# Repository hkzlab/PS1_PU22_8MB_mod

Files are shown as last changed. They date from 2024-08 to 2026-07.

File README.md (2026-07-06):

# PlayStation PU-22 8MB RAM Daughterboard

## DISCLAIMER

Any use of this project is **under your own responsibility**.
You will be responsible of checking the correct construction and functionality of your board.
By using this project You will agree that I cannot be held responsible if it will destroy any of your devices, damage your computer, burn down your house or whatever.

## Introduction

This daughter board replaces the single main RAM IC on your PU-22 motherboard with 4 2Mx8 ICs, shuffles some address lines and provides your PlayStation with 8MB of addressable memory.

I tested this on my european SCPH-7502 console, with a PU-22 motherboard in it. The board boots fine and all the 8MB are addressable.
It could work on other models too, but as of now, this is the only tested one.

### Support

If you wish to support me in building new hardware and software for old machines, [throw a few euros in my direction via Ko-Fi](https://ko-fi.com/hkzlab) ☕!

### 💰 Selling these boards 💰

I you want to contact me about selling this project, you can reach me via email at `0hkzUNDERSCOREprojects6ATposteoDOTnet` after properly fixing the email address by removing the digits and replacing the uppercase words with the proper characters.

**Contacts via other channels will be ignored**, as it means you did not read this document thoroughly.

"Collaborations" will boil down to the following:

- If you wish to produce and share this project at a loss or at cost, go for it. I am only asking for attribution and to let me know via email.
- If you want to do it for profit, let's discuss it. I'll probably settle for a rough 5% of the profit. Importing components is getting more expensive by the day, so this will contribute to me making future projects available for free.
- I will NOT do customer assistance for you or your customers. This is a hobby, not my job.

If this is not ok for you, you're cordially invited to go bother someone else :)

Authorized sellers will be listed in this README. If you find someone selling my boards without being listed here, it means they're stealing other people's work.

## Hardware

The board was designed with [KiCad](https://kicad.org/) EDA.

The board **MUST** be produced on a flexible PCB!

### Installation instructions

Disassemble your PlayStation, extract the motherboard and make sure the model is a PU-22.

⚠️WARNING⚠️: This mod probably works on all units with this type of RAM and processor, but it has been tested on PU-22 units only, as of now.

Assemble the daughterboard, soldering caps and memory ICs.
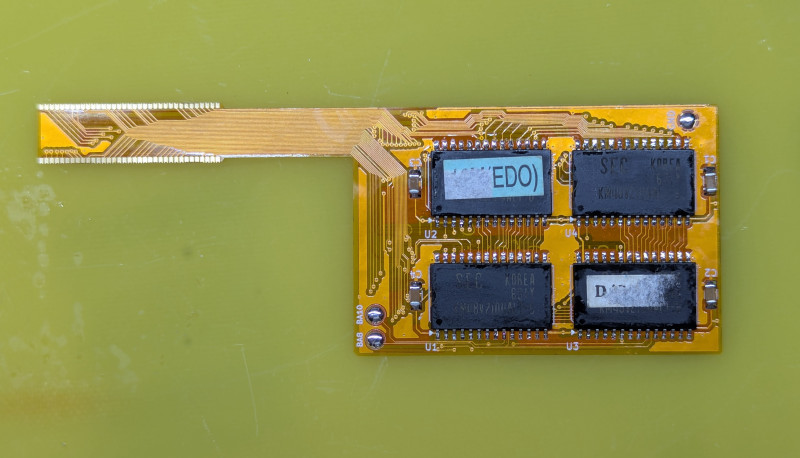
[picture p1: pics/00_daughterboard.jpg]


Desolder the inner shield covering the main ICs, including the RAM.

Cover the components around RAM "IC106" with kapton tape, to protect them during desoldering.
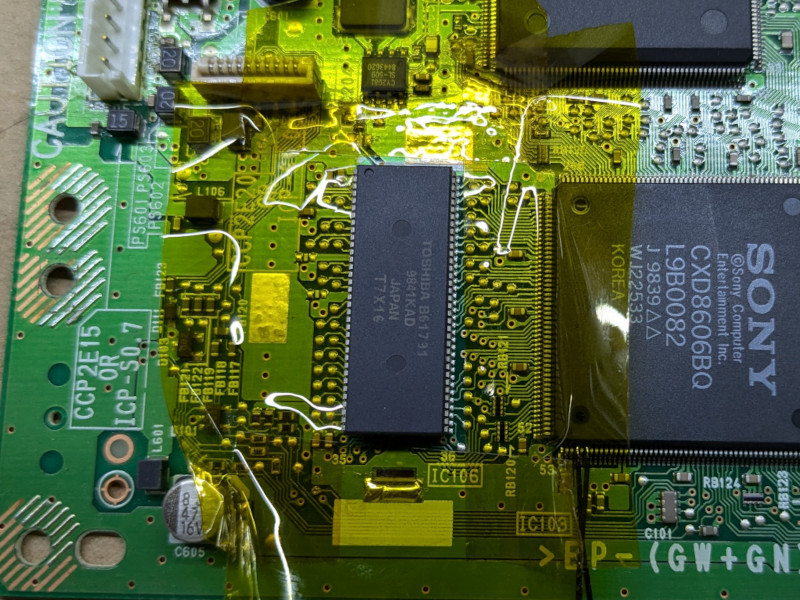
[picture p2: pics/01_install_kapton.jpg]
RAM + Kapton around it


Desolder the RAM IC using hot air, then clean the pads using flux and solder wick.
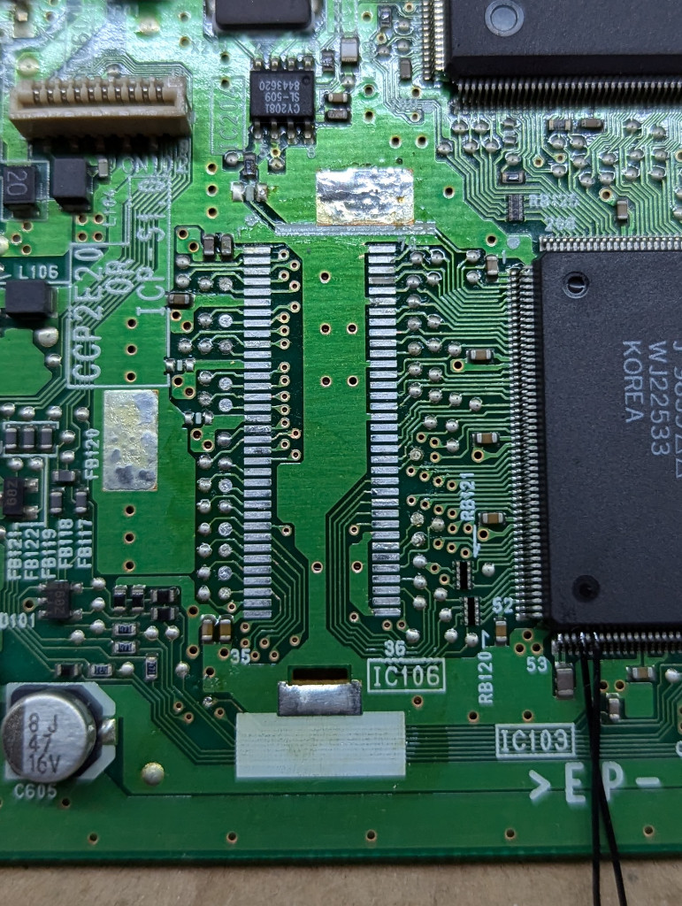
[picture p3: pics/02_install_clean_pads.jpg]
RAM desoldered, pads clean


Solder the board to the old RAM pads, make sure to solder the board in the correct orientation. Pin one has a tiny arrow printed on it, match it on pin 1 on the motherboard.
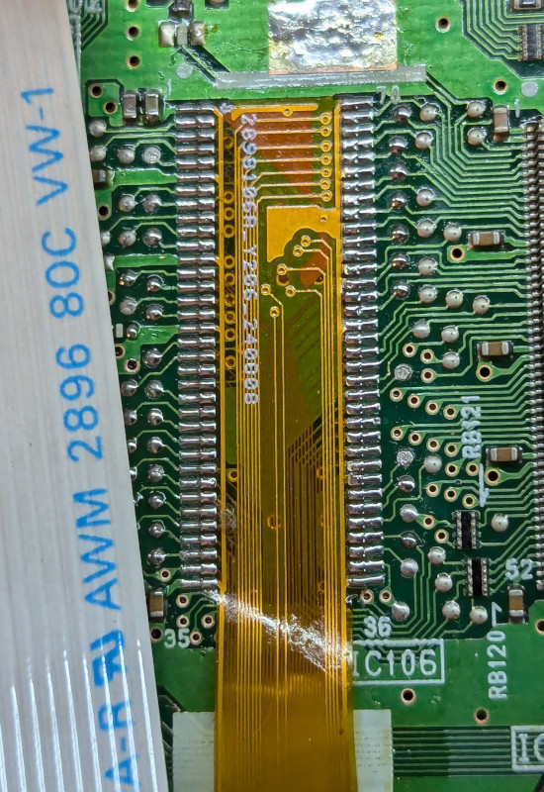
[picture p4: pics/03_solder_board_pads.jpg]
soldered pads


You now need to solder two wires to the CPU, to extract A10 and A8. A10 is pin 56, A8 is pin 58.
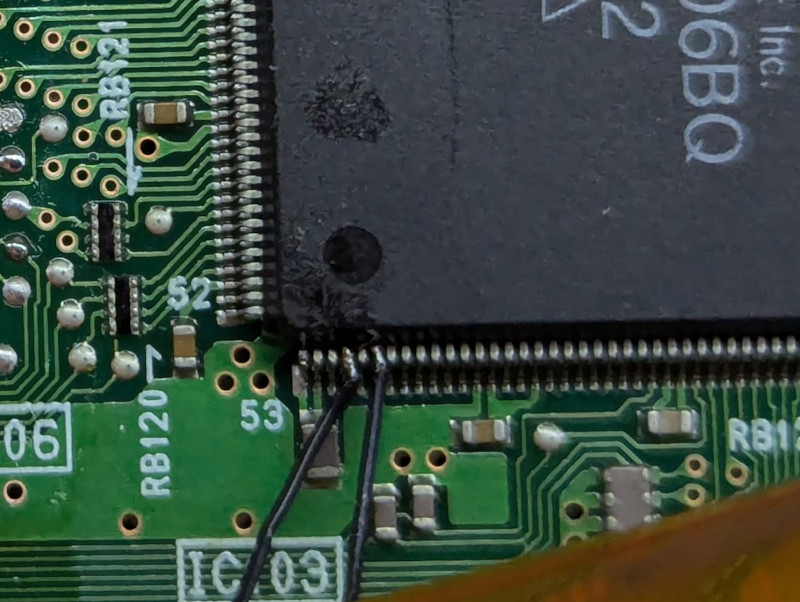
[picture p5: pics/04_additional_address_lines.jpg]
address line soldered


You can then solder these lines to the pads with matching names on the daughterboard.

You can now reinstall the shield, but before inserting it, bend inward the part of the shield that went through the PCB near the RAM pad, make it almost flush to the shield, so it doesn't block the way for the daughterboard to get out.

Once reinstalled, cover the part of the shield where the daughterboard will sit with tape, so there is no chance of shorting.
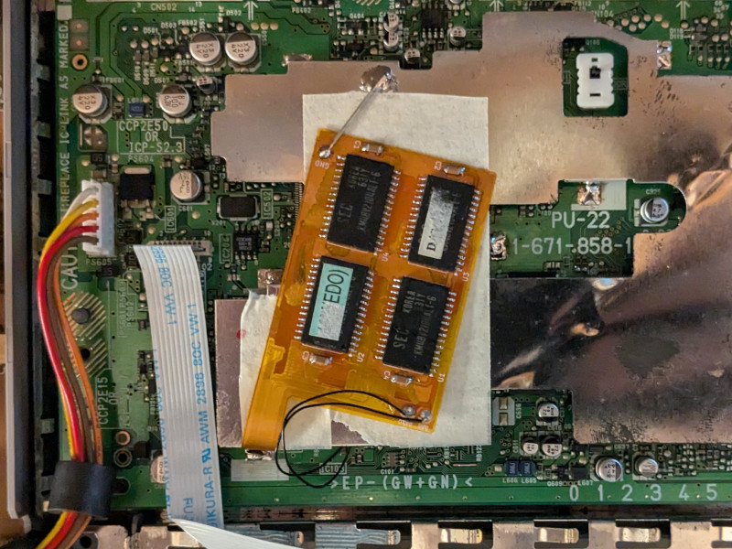
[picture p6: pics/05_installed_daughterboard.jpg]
daughterboard installed


Solder the daughterboard GND pad to the shield, use rigid wire so it keeps the daughterboard in place.

You can put tape over the daughterboard too, to avoid shorting, then reassemble the unit.

### Bill of Materials

| Component | Qty | Type / Value | Notes |
| --- | --- | --- | --- |
| C1 - C4 |  4  | 100nF / 1206 / ceramic | |
| U1 - U4 |  4  | KM48V2104ALT-6 | Compatible memory can be used |

### Ordering the boards

You can order the board for this project at [PCBWay](https://www.pcbway.com/project/shareproject/PlayStation_PU_22_8MB_RAM_Daughterboard_6c497b7f.html) and support me or download 
the gerbers and have them printed wherever you like!!!

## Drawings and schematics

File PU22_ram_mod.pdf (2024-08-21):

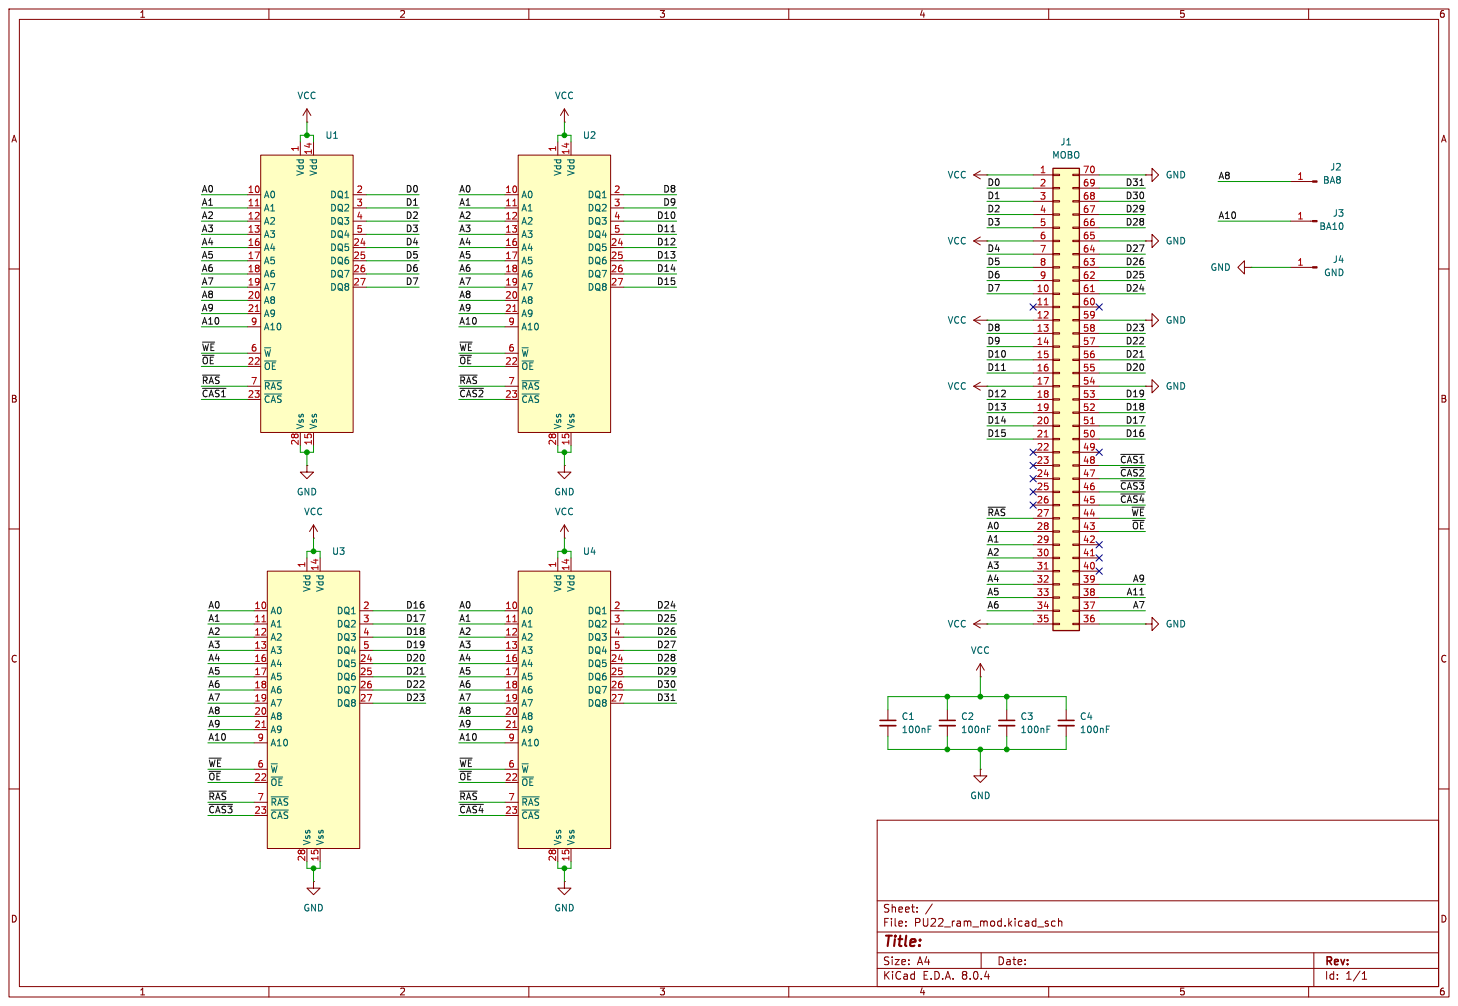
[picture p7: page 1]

Id: 1/1 Title: File: PU22_ram_mod.kicad_sch Sheet: /

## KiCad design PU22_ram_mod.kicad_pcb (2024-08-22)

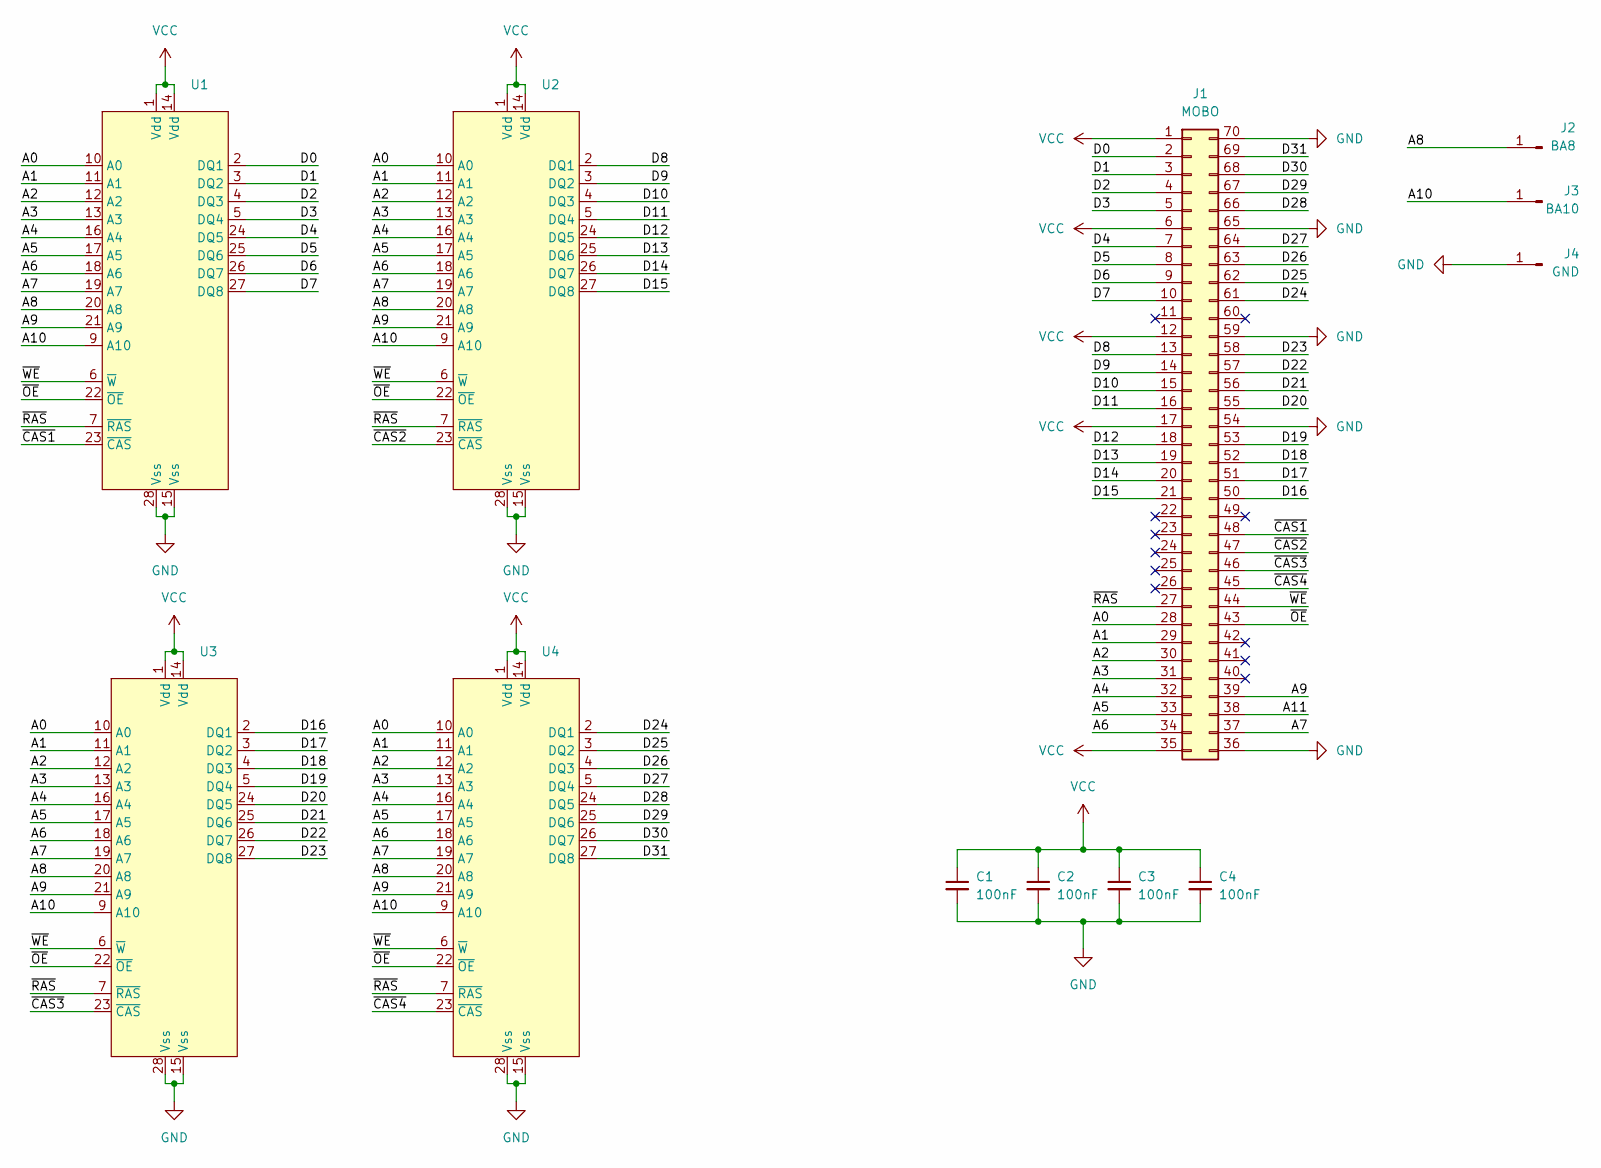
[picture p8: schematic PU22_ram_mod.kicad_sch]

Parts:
C1, C2, C3, C4: 100nF; C_1206_3216Metric_Pad1.33x1.80mm_HandSolder
J1: MOBO; SOJ70_castellated
J2: BA8; TestPoint_Pad_D2.5mm
J3: BA10; TestPoint_Pad_D2.5mm
J4: GND; TestPoint_Pad_D2.5mm
U1, U2, U3, U4: SOP-28_DRAM

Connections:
/A0: J1.28, U1.10 (A0), U2.10 (A0), U3.10 (A0), U4.10 (A0)
/A1: J1.29, U1.11 (A1), U2.11 (A1), U3.11 (A1), U4.11 (A1)
/A2: J1.30, U1.12 (A2), U2.12 (A2), U3.12 (A2), U4.12 (A2)
/A3: J1.31, U1.13 (A3), U2.13 (A3), U3.13 (A3), U4.13 (A3)
/A4: J1.32, U1.16 (A4), U2.16 (A4), U3.16 (A4), U4.16 (A4)
/A5: J1.33, U1.17 (A5), U2.17 (A5), U3.17 (A5), U4.17 (A5)
/A6: J1.34, U1.18 (A6), U2.18 (A6), U3.18 (A6), U4.18 (A6)
/A7: J1.37, U1.19 (A7), U2.19 (A7), U3.19 (A7), U4.19 (A7)
/A8: J2.1, U1.20 (A8), U2.20 (A8), U3.20 (A8), U4.20 (A8)
/A9: J1.39, U1.21 (A9), U2.21 (A9), U3.21 (A9), U4.21 (A9)
/A10: J3.1, U1.9 (A10), U2.9 (A10), U3.9 (A10), U4.9 (A10)
/A11: J1.38
/D0: J1.2, U1.2 (DQ1)
/D1: J1.3, U1.3 (DQ2)
/D2: J1.4, U1.4 (DQ3)
/D3: J1.5, U1.5 (DQ4)
/D4: J1.7, U1.24 (DQ5)
/D5: J1.8, U1.25 (DQ6)
/D6: J1.9, U1.26 (DQ7)
/D7: J1.10, U1.27 (DQ8)
/D8: J1.13, U2.2 (DQ1)
/D9: J1.14, U2.3 (DQ2)
/D10: J1.15, U2.4 (DQ3)
/D11: J1.16, U2.5 (DQ4)
/D12: J1.18, U2.24 (DQ5)
/D13: J1.19, U2.25 (DQ6)
/D14: J1.20, U2.26 (DQ7)
/D15: J1.21, U2.27 (DQ8)
/D16: J1.50, U3.2 (DQ1)
/D17: J1.51, U3.3 (DQ2)
/D18: J1.52, U3.4 (DQ3)
/D19: J1.53, U3.5 (DQ4)
/D20: J1.55, U3.24 (DQ5)
/D21: J1.56, U3.25 (DQ6)
/D22: J1.57, U3.26 (DQ7)
/D23: J1.58, U3.27 (DQ8)
/D24: J1.61, U4.2 (DQ1)
/D25: J1.62, U4.3 (DQ2)
/D26: J1.63, U4.4 (DQ3)
/D27: J1.64, U4.5 (DQ4)
/D28: J1.66, U4.24 (DQ5)
/D29: J1.67, U4.25 (DQ6)
/D30: J1.68, U4.26 (DQ7)
/D31: J1.69, U4.27 (DQ8)
/~CAS1: J1.48, U1.23 (~CAS)
/~CAS2: J1.47, U2.23 (~CAS)
/~CAS3: J1.46, U3.23 (~CAS)
/~CAS4: J1.45, U4.23 (~CAS)
/~OE: J1.43, U1.22 (~OE), U2.22 (~OE), U3.22 (~OE), U4.22 (~OE)
/~RAS: J1.27, U1.7 (~RAS), U2.7 (~RAS), U3.7 (~RAS), U4.7 (~RAS)
/~WE: J1.44, U1.6 (~W), U2.6 (~W), U3.6 (~W), U4.6 (~W)
GND: C1.2, C2.2, C3.2, C4.2, J1.36, J1.54, J1.59, J1.65, J1.70, J4.1, U1.15 (Vss), U1.28 (Vss), U2.15 (Vss), U2.28 (Vss), U3.15 (Vss), U3.28 (Vss), U4.15 (Vss), U4.28 (Vss)
VCC: C1.1, C2.1, C3.1, C4.1, J1.1, J1.6, J1.12, J1.17, J1.35, U1.1 (Vdd), U1.14 (Vdd), U2.1 (Vdd), U2.14 (Vdd), U3.1 (Vdd), U3.14 (Vdd), U4.1 (Vdd), U4.14 (Vdd)

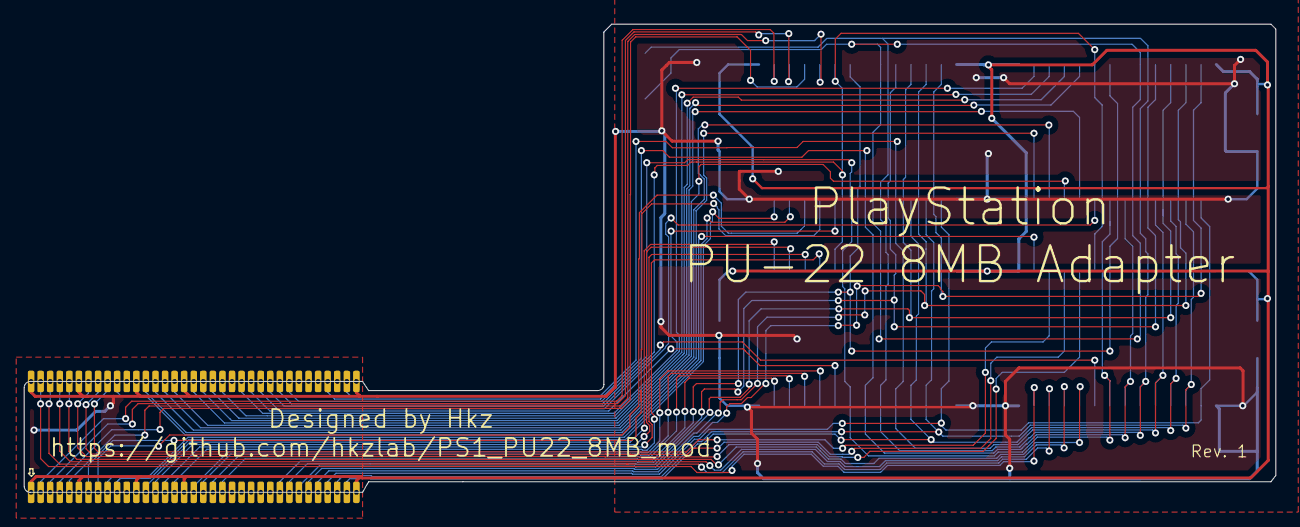
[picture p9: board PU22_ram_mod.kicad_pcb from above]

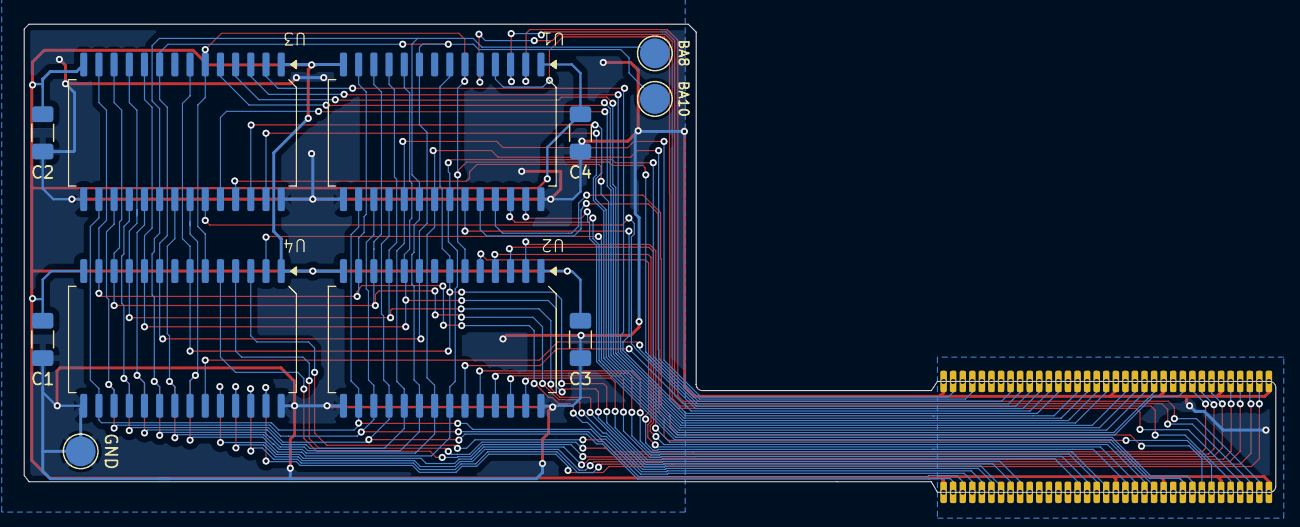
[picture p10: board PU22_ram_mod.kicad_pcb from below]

Board: 2 copper layers, 104.6 x 39.1 mm, 12 parts (11 on the bottom side), 52 nets.

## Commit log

2024-07-30 Add basic needed footprints
2024-07-30 Begin drawing the schematic to expand the memory
    [PU22_ram_mod.kicad_sch]
2024-07-31 Update schematic
    [PU22_ram_mod.kicad_pcb, PU22_ram_mod.kicad_sch]
2024-07-31 Some tracing
    [PU22_ram_mod.kicad_pcb]
2024-07-31 some more organizing
    [PU22_ram_mod.kicad_pcb]
2024-08-01 Some routing
    [PU22_ram_mod.kicad_pcb, PU22_ram_mod.kicad_sch]
2024-08-01 Update traces
    [PU22_ram_mod.kicad_pcb]
2024-08-01 Tweaked traces a bit
    [PU22_ram_mod.kicad_pcb]
2024-08-02 make PCB a bit longer
    [PU22_ram_mod.kicad_pcb]
2024-08-02 Change outline
    [PU22_ram_mod.kicad_pcb]
2024-08-06 Reroute traces
    [PU22_ram_mod.kicad_pcb]
2024-08-06 More routing
    [PU22_ram_mod.kicad_pcb]
2024-08-06 Add copper fill in the zone with RAMs
    [PU22_ram_mod.kicad_pcb, PU22_ram_mod.kicad_sch]
2024-08-06 Some more ground plane
    [PU22_ram_mod.kicad_pcb]
2024-08-07 Update the routing of some traces to increase distance from pads
    [PU22_ram_mod.kicad_pcb]
2024-08-07 Readd refill
    [PU22_ram_mod.kicad_pcb]
2024-08-07 more fixes
    [PU22_ram_mod.kicad_pcb]
2024-08-07 Added silkscreen
    [PU22_ram_mod.kicad_pcb]
2024-08-07 Add some gnd filling in soldered connector too
    [PU22_ram_mod.kicad_pcb]
2024-08-21 Add schematics and readme
2024-08-22 Update silkscreen, begin writing small tutorial
    [PU22_ram_mod.kicad_pcb]
2025-09-07 Update the README mentioning producing on PCBWay
